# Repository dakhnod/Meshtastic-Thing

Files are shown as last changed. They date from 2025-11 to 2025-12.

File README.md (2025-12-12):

# Meshtastic-Thing

## Version 1/2







This board is a bit cleaner. It is composed of
- an esp32c3 super mini board
- an RFM95 board
- the PCB, as found in [the kicad folder](kicad/)

This PCB has two mino versions, with the second one labeled `v2`.
The first one connects `DIO0` with the ESP pin 8, which renders the built-in LED unusable.

The second version fixes this. Currently, the kicad Project contains the second version, but the variants.h file still uses GPIO8. You need to adjust this file if using the provided PCB.

Once I receive the second version and test it I will update this repository.

Steps:
1. Get an esp32c3 super mini board.
2. Get an RFM95 module
3. Solder up all boards as seen in the pictures
4. Clone the meshtastic firmware repo (recursively)
5. Open the repo firm VSCode with PlatformIO
6. Change out the file `variants/esp32c3/diy/esp32c3_super_mini/variant.h` to [the one](variants/esp32c3/diy/esp32c3_super_mini/variant.h) in this repo
7. If using the PCB from this repo, update the variants.h file to use pin 9 for DIO0
8. Build and flash the PlatformIO configuration `env:esp32c3_super_mini`
9. Check out [BLEnky](https://structure.nullco.de/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) (unrelated, just wanted to advertise)
10. ???
11. Profit

## Version 0

Weird Meshtastic prototype I build.
For everyone wanting to replicate this (for reasons beyond me), here is some information.
Keep in mind that this instruction requires some skill level. If you have questions, open an issue!

Steps:
1. Get a Board like the one shown in the AliExpress listing (could also be black, doesn't matter. Open an issue if you're unsure)
2. Get an RFM95 module
3. Solder everything up according to the pictures (pin definition in [variant.h](variants/nrf52840/diy/nrf52_promicro_diy_xtal/variant.h))
4. Clone the meshtastic firmware repo (recursively)
5. Open the repo firm VSCode with PlatformIO
6. Change out the file `variants/nrf52840/diy/nrf52_promicro_diy_xtal/variant.h` to the one in this repo
7. Build and flash the PlatformIO configuration `env:nrf52_promicro_diy_xtal`
8. Check out [BLEnky](https://structure.nullco.de/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) (unrelated, just wanted to advertise)
9. ???
10. Profit











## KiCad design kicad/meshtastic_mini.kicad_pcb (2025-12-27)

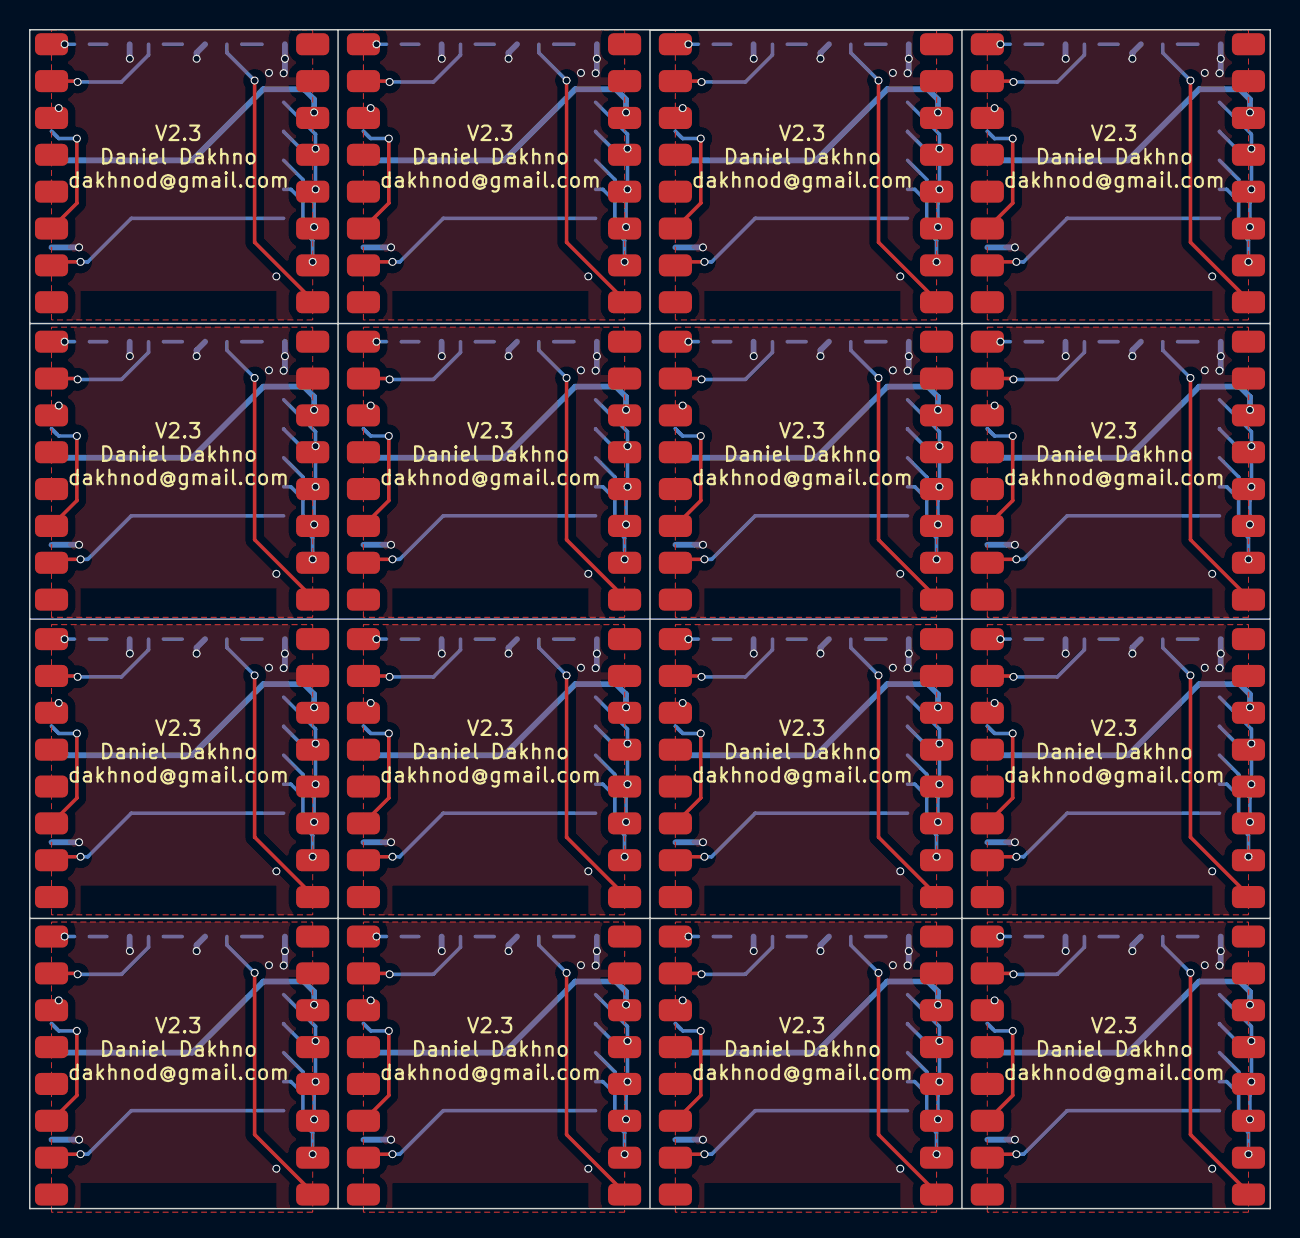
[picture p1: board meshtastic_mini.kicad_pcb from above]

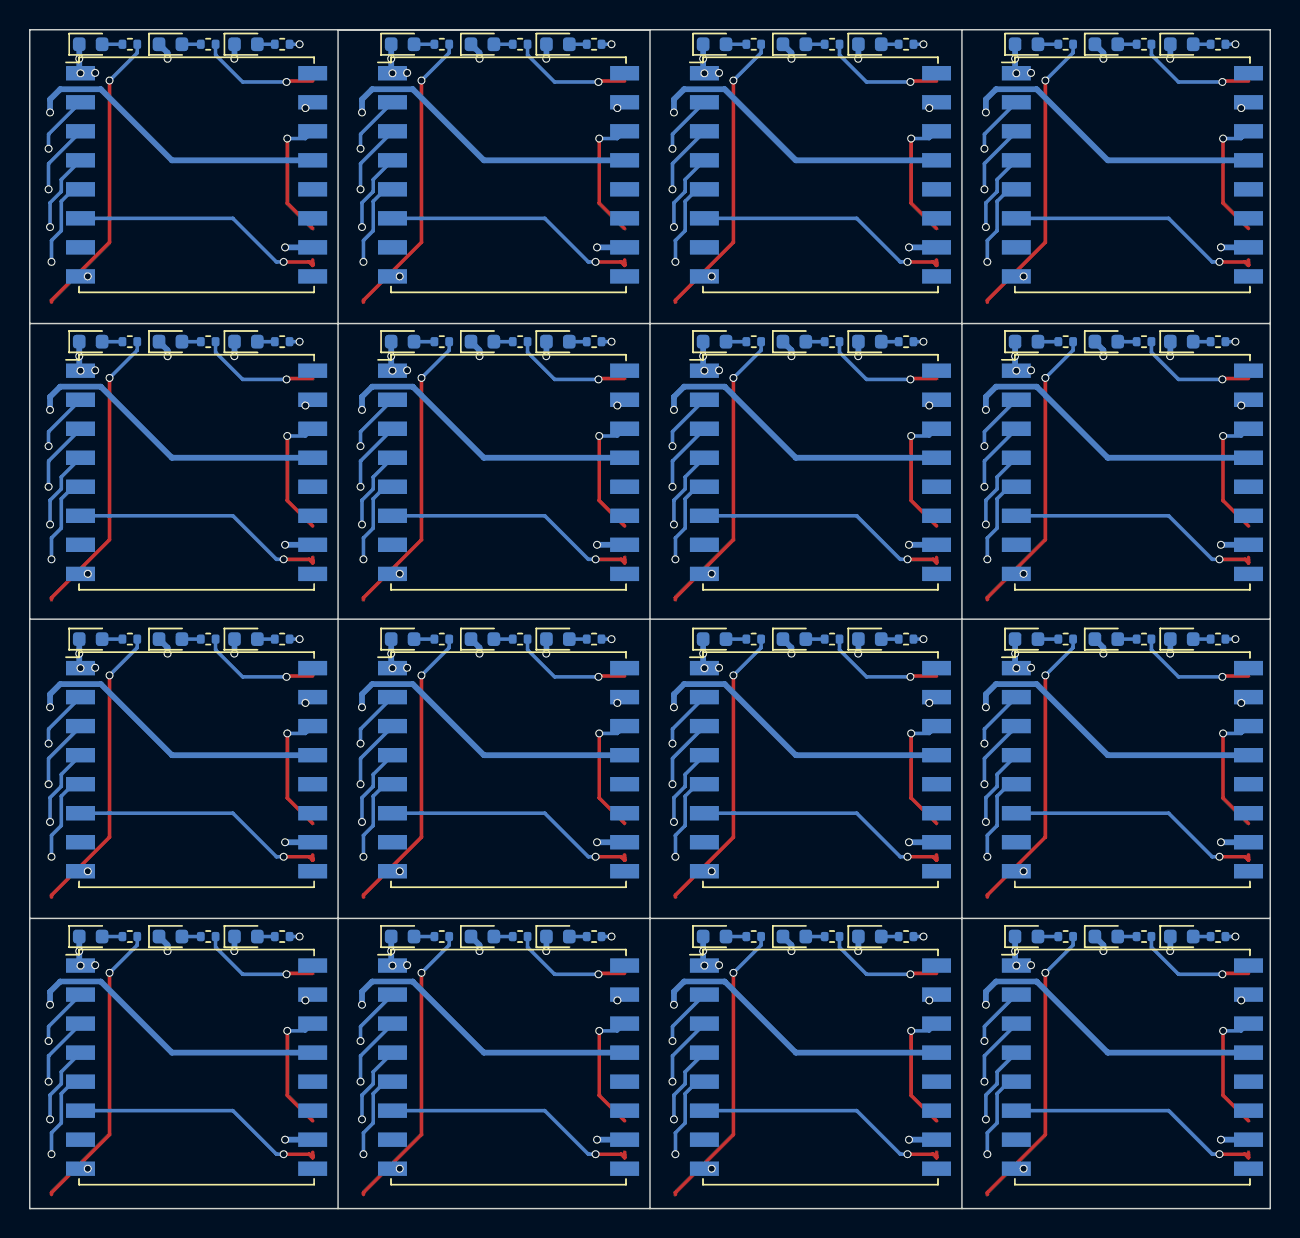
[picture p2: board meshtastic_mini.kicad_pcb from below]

Board: 2 copper layers, 85.5 x 81.2 mm, 128 parts (112 on the bottom side), 15 nets.

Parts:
D1, D2, D3, D4, D5, D6, D7, D8, D9, D10, D11, D12, D13, D14, D15, D16, D17, D18, D19, D20, D21, D22, D23, D24, D25, D26, D27, D28, D29, D30, D31, D32, D33, D34, D35, D36, D37, D38, D39, D40, D41, D42, D43, D44, D45, D46, D47, D48: LED; LED_0603_1608Metric
R1, R2, R3, R4, R5, R6, R7, R8, R9, R10, R11, R12, R13, R14, R15, R16, R17, R18, R19, R20, R21, R22, R23, R24, R25, R26, R27, R28, R29, R30, R31, R32, R33, R34, R35, R36, R37, R38, R39, R40, R41, R42, R43, R44, R45, R46, R47, R48: 1K; R_0402_1005Metric
U1, U3, U5, U7, U9, U11, U13, U15, U17, U19, U21, U23, U25, U27, U29, U31: ESP32-C3_SuperMini; ESP32-C3 SuperMini
U2, U4, U6, U8, U10, U12, U14, U16, U18, U20, U22, U24, U26, U28, U30, U32: RFM95W-868S2; HOPERF_RFM9XW_SMD

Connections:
+3.3V: U1.11 (3V3), U2.13 (3.3V), U3.11 (3V3), U4.13 (3.3V), U5.11 (3V3), U6.13 (3.3V), U7.11 (3V3), U8.13 (3.3V), U9.11 (3V3), U10.13 (3.3V), U11.11 (3V3), U12.13 (3.3V), U13.11 (3V3), U14.13 (3.3V), U15.11 (3V3), U16.13 (3.3V), U17.11 (3V3), U18.13 (3.3V), U19.11 (3V3), U20.13 (3.3V), U21.11 (3V3), U22.13 (3.3V), U23.11 (3V3), U24.13 (3.3V), U25.11 (3V3), U26.13 (3.3V), U27.11 (3V3), U28.13 (3.3V), U29.11 (3V3), U30.13 (3.3V), U31.11 (3V3), U32.13 (3.3V)
/DIO0: U1.6 (GPIO10), U2.14 (DIO0), U3.6 (GPIO10), U4.14 (DIO0), U5.6 (GPIO10), U6.14 (DIO0), U7.6 (GPIO10), U8.14 (DIO0), U9.6 (GPIO10), U10.14 (DIO0), U11.6 (GPIO10), U12.14 (DIO0), U13.6 (GPIO10), U14.14 (DIO0), U15.6 (GPIO10), U16.14 (DIO0), U17.6 (GPIO10), U18.14 (DIO0), U19.6 (GPIO10), U20.14 (DIO0), U21.6 (GPIO10), U22.14 (DIO0), U23.6 (GPIO10), U24.14 (DIO0), U25.6 (GPIO10), U26.14 (DIO0), U27.6 (GPIO10), U28.14 (DIO0), U29.6 (GPIO10), U30.14 (DIO0), U31.6 (GPIO10), U32.14 (DIO0)
/DIO1: U1.3 (GPIO7), U2.15 (DIO1), U3.3 (GPIO7), U4.15 (DIO1), U5.3 (GPIO7), U6.15 (DIO1), U7.3 (GPIO7), U8.15 (DIO1), U9.3 (GPIO7), U10.15 (DIO1), U11.3 (GPIO7), U12.15 (DIO1), U13.3 (GPIO7), U14.15 (DIO1), U15.3 (GPIO7), U16.15 (DIO1), U17.3 (GPIO7), U18.15 (DIO1), U19.3 (GPIO7), U20.15 (DIO1), U21.3 (GPIO7), U22.15 (DIO1), U23.3 (GPIO7), U24.15 (DIO1), U25.3 (GPIO7), U26.15 (DIO1), U27.3 (GPIO7), U28.15 (DIO1), U29.3 (GPIO7), U30.15 (DIO1), U31.3 (GPIO7), U32.15 (DIO1)
/RESET: U1.7 (GPIO20), U2.6 (RESET), U3.7 (GPIO20), U4.6 (RESET), U5.7 (GPIO20), U6.6 (RESET), U7.7 (GPIO20), U8.6 (RESET), U9.7 (GPIO20), U10.6 (RESET), U11.7 (GPIO20), U12.6 (RESET), U13.7 (GPIO20), U14.6 (RESET), U15.7 (GPIO20), U16.6 (RESET), U17.7 (GPIO20), U18.6 (RESET), U19.7 (GPIO20), U20.6 (RESET), U21.7 (GPIO20), U22.6 (RESET), U23.7 (GPIO20), U24.6 (RESET), U25.7 (GPIO20), U26.6 (RESET), U27.7 (GPIO20), U28.6 (RESET), U29.7 (GPIO20), U30.6 (RESET), U31.7 (GPIO20), U32.6 (RESET)
/SPI_MISO: U1.12 (GPIO4), U2.2 (MISO), U3.12 (GPIO4), U4.2 (MISO), U5.12 (GPIO4), U6.2 (MISO), U7.12 (GPIO4), U8.2 (MISO), U9.12 (GPIO4), U10.2 (MISO), U11.12 (GPIO4), U12.2 (MISO), U13.12 (GPIO4), U14.2 (MISO), U15.12 (GPIO4), U16.2 (MISO), U17.12 (GPIO4), U18.2 (MISO), U19.12 (GPIO4), U20.2 (MISO), U21.12 (GPIO4), U22.2 (MISO), U23.12 (GPIO4), U24.2 (MISO), U25.12 (GPIO4), U26.2 (MISO), U27.12 (GPIO4), U28.2 (MISO), U29.12 (GPIO4), U30.2 (MISO), U31.12 (GPIO4), U32.2 (MISO)
/SPI_MOSI: U1.13 (GPIO3), U2.3 (MOSI), U3.13 (GPIO3), U4.3 (MOSI), U5.13 (GPIO3), U6.3 (MOSI), U7.13 (GPIO3), U8.3 (MOSI), U9.13 (GPIO3), U10.3 (MOSI), U11.13 (GPIO3), U12.3 (MOSI), U13.13 (GPIO3), U14.3 (MOSI), U15.13 (GPIO3), U16.3 (MOSI), U17.13 (GPIO3), U18.3 (MOSI), U19.13 (GPIO3), U20.3 (MOSI), U21.13 (GPIO3), U22.3 (MOSI), U23.13 (GPIO3), U24.3 (MOSI), U25.13 (GPIO3), U26.3 (MOSI), U27.13 (GPIO3), U28.3 (MOSI), U29.13 (GPIO3), U30.3 (MOSI), U31.13 (GPIO3), U32.3 (MOSI)
/SPI_NSS: U1.15 (GPIO1), U2.5 (NSS), U3.15 (GPIO1), U4.5 (NSS), U5.15 (GPIO1), U6.5 (NSS), U7.15 (GPIO1), U8.5 (NSS), U9.15 (GPIO1), U10.5 (NSS), U11.15 (GPIO1), U12.5 (NSS), U13.15 (GPIO1), U14.5 (NSS), U15.15 (GPIO1), U16.5 (NSS), U17.15 (GPIO1), U18.5 (NSS), U19.15 (GPIO1), U20.5 (NSS), U21.15 (GPIO1), U22.5 (NSS), U23.15 (GPIO1), U24.5 (NSS), U25.15 (GPIO1), U26.5 (NSS), U27.15 (GPIO1), U28.5 (NSS), U29.15 (GPIO1), U30.5 (NSS), U31.15 (GPIO1), U32.5 (NSS)
/SPI_SCK: U1.14 (GPIO2), U2.4 (SCK), U3.14 (GPIO2), U4.4 (SCK), U5.14 (GPIO2), U6.4 (SCK), U7.14 (GPIO2), U8.4 (SCK), U9.14 (GPIO2), U10.4 (SCK), U11.14 (GPIO2), U12.4 (SCK), U13.14 (GPIO2), U14.4 (SCK), U15.14 (GPIO2), U16.4 (SCK), U17.14 (GPIO2), U18.4 (SCK), U19.14 (GPIO2), U20.4 (SCK), U21.14 (GPIO2), U22.4 (SCK), U23.14 (GPIO2), U24.4 (SCK), U25.14 (GPIO2), U26.4 (SCK), U27.14 (GPIO2), U28.4 (SCK), U29.14 (GPIO2), U30.4 (SCK), U31.14 (GPIO2), U32.4 (SCK)
GND: D1.1 (K), D2.1 (K), D3.1 (K), D4.1 (K), D5.1 (K), D6.1 (K), D7.1 (K), D8.1 (K), D9.1 (K), D10.1 (K), D11.1 (K), D12.1 (K), D13.1 (K), D14.1 (K), D15.1 (K), D16.1 (K), D17.1 (K), D18.1 (K), D19.1 (K), D20.1 (K), D21.1 (K), D22.1 (K), D23.1 (K), D24.1 (K), D25.1 (K), D26.1 (K), D27.1 (K), D28.1 (K), D29.1 (K), D30.1 (K), D31.1 (K), D32.1 (K), D33.1 (K), D34.1 (K), D35.1 (K), D36.1 (K), D37.1 (K), D38.1 (K), D39.1 (K), D40.1 (K), D41.1 (K), D42.1 (K), D43.1 (K), D44.1 (K), D45.1 (K), D46.1 (K), D47.1 (K), D48.1 (K), U1.10 (GND), U2.1 (GND), U2.8 (GND), U2.10 (GND), U3.10 (GND), U4.1 (GND), U4.8 (GND), U4.10 (GND), U5.10 (GND), U6.1 (GND), U6.8 (GND), U6.10 (GND), U7.10 (GND), U8.1 (GND), U8.8 (GND), U8.10 (GND), U9.10 (GND), U10.1 (GND), U10.8 (GND), U10.10 (GND), U11.10 (GND), U12.1 (GND), U12.8 (GND), U12.10 (GND), U13.10 (GND), U14.1 (GND), U14.8 (GND), U14.10 (GND), U15.10 (GND), U16.1 (GND), U16.8 (GND), U16.10 (GND), U17.10 (GND), U18.1 (GND), U18.8 (GND), U18.10 (GND), U19.10 (GND), U20.1 (GND), U20.8 (GND), U20.10 (GND), U21.10 (GND), U22.1 (GND), U22.8 (GND), U22.10 (GND), U23.10 (GND), U24.1 (GND), U24.8 (GND), U24.10 (GND), U25.10 (GND), U26.1 (GND), U26.8 (GND), U26.10 (GND), U27.10 (GND), U28.1 (GND), U28.8 (GND), U28.10 (GND), U29.10 (GND), U30.1 (GND), U30.8 (GND), U30.10 (GND), U31.10 (GND), U32.1 (GND), U32.8 (GND), U32.10 (GND)
unnamed: D1.2 (A), D4.2 (A), D7.2 (A), D10.2 (A), D13.2 (A), D16.2 (A), D19.2 (A), D22.2 (A), D25.2 (A), D28.2 (A), D31.2 (A), D34.2 (A), D37.2 (A), D40.2 (A), D43.2 (A), D46.2 (A), R1.2, R4.2, R7.2, R10.2, R13.2, R16.2, R19.2, R22.2, R25.2, R28.2, R31.2, R34.2, R37.2, R40.2, R43.2, R46.2
unnamed: D2.2 (A), D5.2 (A), D8.2 (A), D11.2 (A), D14.2 (A), D17.2 (A), D20.2 (A), D23.2 (A), D26.2 (A), D29.2 (A), D32.2 (A), D35.2 (A), D38.2 (A), D41.2 (A), D44.2 (A), D47.2 (A), R2.2, R5.2, R8.2, R11.2, R14.2, R17.2, R20.2, R23.2, R26.2, R29.2, R32.2, R35.2, R38.2, R41.2, R44.2, R47.2
unnamed: D3.2 (A), D6.2 (A), D9.2 (A), D12.2 (A), D15.2 (A), D18.2 (A), D21.2 (A), D24.2 (A), D27.2 (A), D30.2 (A), D33.2 (A), D36.2 (A), D39.2 (A), D42.2 (A), D45.2 (A), D48.2 (A), R3.2, R6.2, R9.2, R12.2, R15.2, R18.2, R21.2, R24.2, R27.2, R30.2, R33.2, R36.2, R39.2, R42.2, R45.2, R48.2
unnamed: R3.1, R6.1, R9.1, R12.1, R15.1, R18.1, R21.1, R24.1, R27.1, R30.1, R33.1, R36.1, R39.1, R42.1, R45.1, R48.1, U1.16 (GPIO0), U3.16 (GPIO0), U5.16 (GPIO0), U7.16 (GPIO0), U9.16 (GPIO0), U11.16 (GPIO0), U13.16 (GPIO0), U15.16 (GPIO0), U17.16 (GPIO0), U19.16 (GPIO0), U21.16 (GPIO0), U23.16 (GPIO0), U25.16 (GPIO0), U27.16 (GPIO0), U29.16 (GPIO0), U31.16 (GPIO0)
unnamed: R1.1, R4.1, R7.1, R10.1, R13.1, R16.1, R19.1, R22.1, R25.1, R28.1, R31.1, R34.1, R37.1, R40.1, R43.1, R46.1, U1.1 (GPIO5), U3.1 (GPIO5), U5.1 (GPIO5), U7.1 (GPIO5), U9.1 (GPIO5), U11.1 (GPIO5), U13.1 (GPIO5), U15.1 (GPIO5), U17.1 (GPIO5), U19.1 (GPIO5), U21.1 (GPIO5), U23.1 (GPIO5), U25.1 (GPIO5), U27.1 (GPIO5), U29.1 (GPIO5), U31.1 (GPIO5)
unnamed: R2.1, R5.1, R8.1, R11.1, R14.1, R17.1, R20.1, R23.1, R26.1, R29.1, R32.1, R35.1, R38.1, R41.1, R44.1, R47.1, U1.2 (GPIO6), U3.2 (GPIO6), U5.2 (GPIO6), U7.2 (GPIO6), U9.2 (GPIO6), U11.2 (GPIO6), U13.2 (GPIO6), U15.2 (GPIO6), U17.2 (GPIO6), U19.2 (GPIO6), U21.2 (GPIO6), U23.2 (GPIO6), U25.2 (GPIO6), U27.2 (GPIO6), U29.2 (GPIO6), U31.2 (GPIO6)

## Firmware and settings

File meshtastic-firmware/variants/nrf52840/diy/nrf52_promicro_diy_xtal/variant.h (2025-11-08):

#ifndef _VARIANT_PROMICRO_DIY_
#define _VARIANT_PROMICRO_DIY_

/** Master clock frequency */
#define VARIANT_MCK (64000000ul)

#define USE_LFXO // Board uses 32khz crystal for LF
// #define USE_LFRC // Board uses RC for LF

#define PROMICRO_DIY_XTAL
/*----------------------------------------------------------------------------
 *        Headers
 *----------------------------------------------------------------------------*/

#include "WVariant.h"

#ifdef __cplusplus
extern "C"
{
#endif // __cplusplus

// Number of pins defined in PinDescription array
#define PINS_COUNT (48)
#define NUM_DIGITAL_PINS (48)
#define NUM_ANALOG_INPUTS (0)
#define NUM_ANALOG_OUTPUTS (0)

// Pin 13 enables 3.3V periphery. If the Lora module is on this pin, then it should stay enabled at all times.
#define PIN_3V3_EN (0 + 13) // P0.13

    // WIRE IC AND IIC PINS
    // #define WIRE_INTERFACES_COUNT 1

#define MESHTASTIC_EXCLUDE_GPS 1
#define MESHTASTIC_EXCLUDE_SCREEN 1

#define WIRE_INTERFACES_COUNT 1

#define PIN_WIRE_SDA (32 + 4) // P1.04
#define PIN_WIRE_SCL (0 + 11) // P0.11

// LED
#define PIN_LED1 (0 + 15) // P0.15
#define LED_BUILTIN PIN_LED1
// Actually red
#define LED_BLUE PIN_LED1
#define LED_STATE_ON 1 // State when LED is lit

// UART interfaces
#define PIN_SERIAL1_RX (32 + 0)
#define PIN_SERIAL1_TX (32 + 24)

#define PIN_SERIAL2_RX (0 + 29)
#define PIN_SERIAL2_TX (0 + 31)

// Serial interfaces
#define SPI_INTERFACES_COUNT 1

#define PIN_SPI_MISO (0 + 2)   // P0.02
#define PIN_SPI_MOSI (32 + 15) // P1.15
#define PIN_SPI_SCK (32 + 13)  // P1.11

#define LORA_CS (32 + 11)
#define LORA_RESET (0 + 10)

#define USE_RF95

#define LORA_DIO1 (0 + 22)
#define LORA_DIO0 (0 + 24)

#ifdef __cplusplus
}
#endif

/*----------------------------------------------------------------------------
 *        Arduino objects - C++ only
 *----------------------------------------------------------------------------*/

#endif

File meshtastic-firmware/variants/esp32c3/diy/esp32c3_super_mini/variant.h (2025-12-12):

#ifndef _VARIANT_ESP32C3_SUPER_MINI_
#define _VARIANT_ESP32C3_SUPER_MINI_

/*----------------------------------------------------------------------------
 *        Headers
 *----------------------------------------------------------------------------*/

#ifdef __cplusplus
extern "C" {
#endif // __cplusplus

// I2C (Wire) & OLED
#define WIRE_INTERFACES_COUNT (1)
#define I2C_SDA (5)
#define I2C_SCL (6)

#define USE_SSD1306

// GPS
#undef GPS_RX_PIN
#undef GPS_TX_PIN
#define GPS_RX_PIN (20)
#define GPS_TX_PIN (21)

// Button
#define BUTTON_PIN (9) // BOOT button

// LoRa
// #define USE_LLCC68
// #define USE_SX1262
#define USE_RF95
// #define USE_SX1268

#define LORA_DIO0 (8)
#define LORA_RESET (0)
#define LORA_DIO1 (7)
// #define LORA_RXEN (2)
// #define LORA_BUSY (4)
#define LORA_SCK (2)
#define LORA_MISO (4)
#define LORA_MOSI (3)
#define LORA_CS (1)

#ifdef __cplusplus
}
#endif

/*----------------------------------------------------------------------------
 *        Arduino objects - C++ only
 *----------------------------------------------------------------------------*/

#endif

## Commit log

2025-11-08 Enhance README with replication instructions and images
    Expanded instructions for replicating the Meshtastic prototype, including detailed steps and images.
2025-12-12 updated instructions for new board
2025-12-12 added kicad files
    [meshtastic_mini.kicad_pcb, meshtastic_mini.kicad_sch]
2025-12-16 connected DIO0 to pin 10 instead of 9
    [meshtastic_mini.kicad_pcb, meshtastic_mini.kicad_sch]
2025-12-27 fixed third LED wiring (that noone will probably ever use)
    [meshtastic_mini.kicad_pcb, meshtastic_mini.kicad_sch]
2025-12-27 adapted for usage with XIAO nrf52 module
    [meshtastic_mini.kicad_pcb, meshtastic_mini.kicad_sch]
